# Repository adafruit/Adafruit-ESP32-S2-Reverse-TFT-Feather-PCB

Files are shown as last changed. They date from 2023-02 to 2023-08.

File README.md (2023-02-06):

## Adafruit ESP32-S2 Reverse TFT Feather PCB

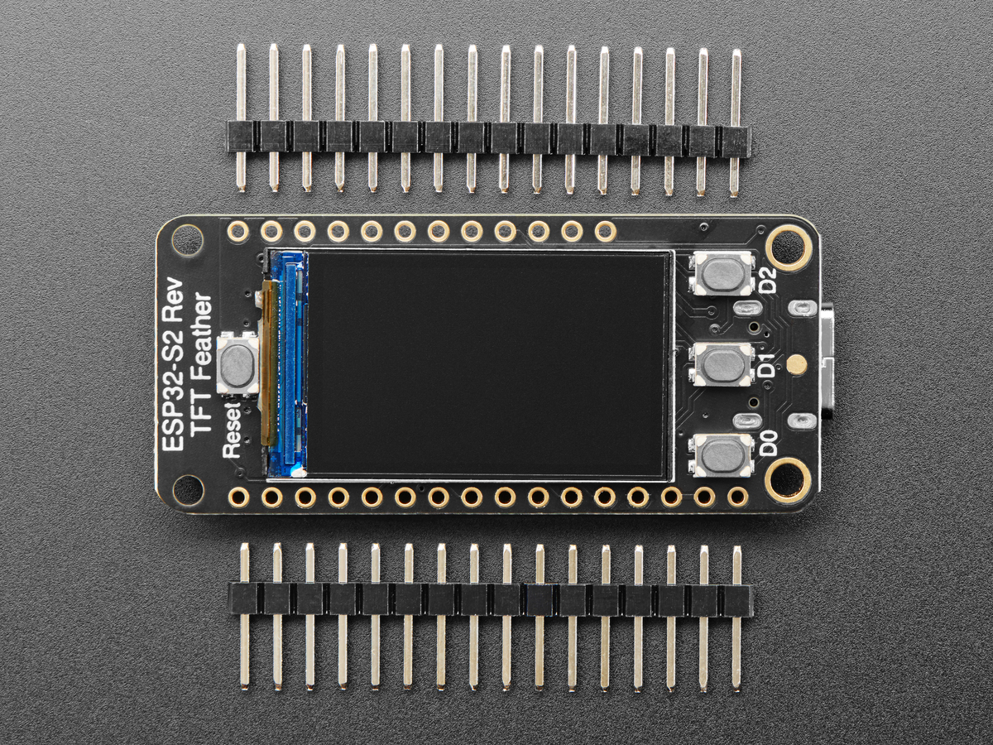
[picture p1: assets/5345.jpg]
<a href="http://www.adafruit.com/products/5345"><br/>
Click here to purchase one from the Adafruit shop</a>

PCB files for the Adafruit ESP32-S2 Reverse TFT Feather. 

Format is EagleCAD schematic and board layout
* https://www.adafruit.com/product/5345

### Description

Like Missy Elliot, we like to "put our [Feather] down, flip it and reverse it" and that's exactly what we've done with this new development board. It's basically our ESP32-S2 TFT Feather but with the 240x135 color TFT display on the back-side not the front-side. That makes it great for panel-mounted projects, particularly since we've also got some space for 3 buttons to go along. It's like an all-in-one display interface dev board, powered by the fantastic ESP32-S2 WIFI module.

This feather comes with native USB and 4 MB flash + 2 MB of PSRAM, so it is perfect for use with CircuitPython or Arduino with low-cost WiFi. Native USB means it can act like a keyboard or a disk drive. WiFi means it's awesome for IoT projects. And Feather means it works with the large community of Feather Wings for expandability.

The ESP32-S2 is a highly-integrated, low-power, 2.4 GHz Wi-Fi System-on-Chip (SoC) solution that now has built-in native USB as well as some other interesting new technologies like Time of Flight distance measurements. With its state-of-the-art power and RF performance, this SoC is an ideal choice for a wide variety of application scenarios relating to the Internet of Things (IoT), wearable electronics, and smart homes.

### License

Adafruit invests time and resources providing this open source design, please support Adafruit and open-source hardware by purchasing products from [Adafruit](https://www.adafruit.com)!

Designed by Limor Fried/Ladyada for Adafruit Industries.

Creative Commons Attribution/Share-Alike, all text above must be included in any redistribution. 
See license.txt for additional details.

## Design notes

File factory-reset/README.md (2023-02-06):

## Factory Reset file - ESP32-S2 Reverse TFT Feather

This is the factory reset file for the ESP32-S2 Reverse TFT Feather.

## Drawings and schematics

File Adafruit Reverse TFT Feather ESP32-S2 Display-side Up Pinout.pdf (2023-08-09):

# Adafruit ESP32-S2 Reverse TFT Feather

# https://www.adafruit.com/product/5345

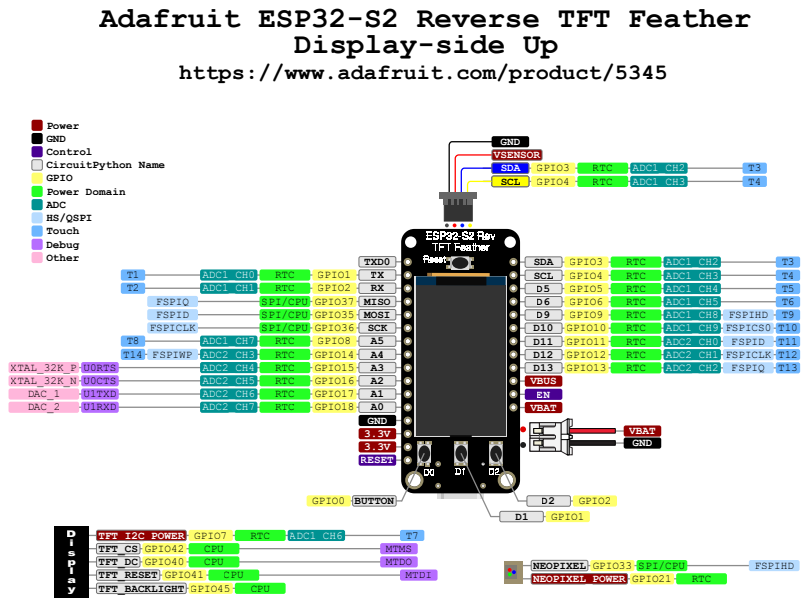
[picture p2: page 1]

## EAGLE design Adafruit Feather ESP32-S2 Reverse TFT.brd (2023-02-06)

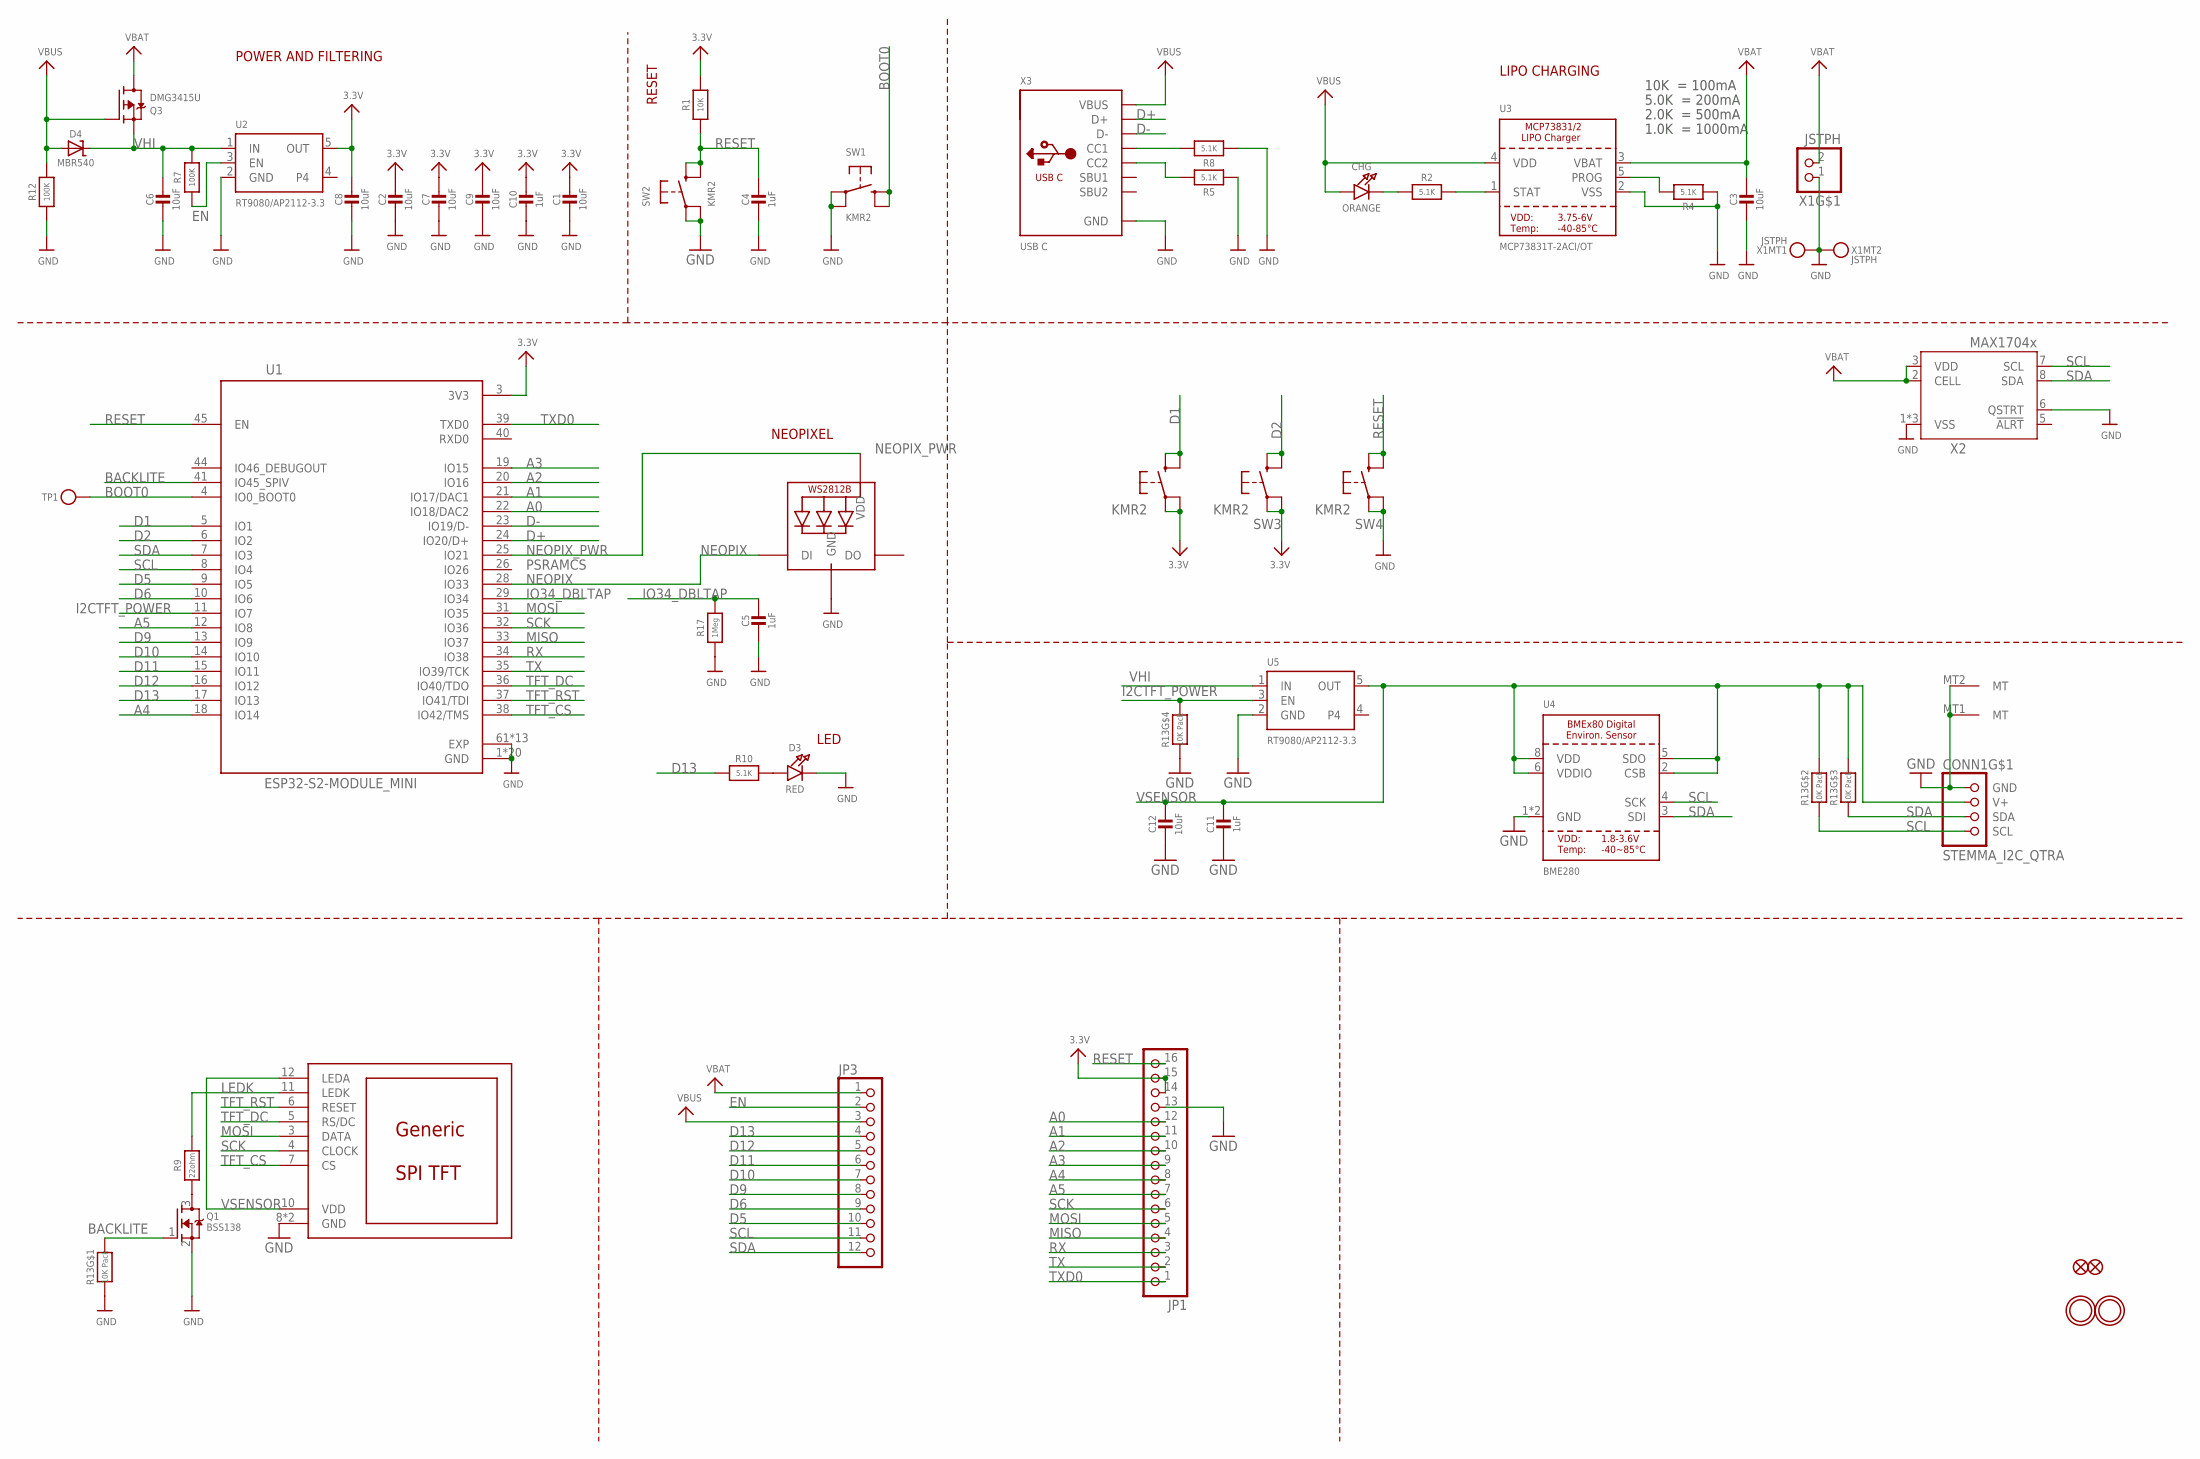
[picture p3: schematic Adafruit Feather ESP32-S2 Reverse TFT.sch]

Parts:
C1, C2, C3, C6, C7, C8, C9, C12: 10uF; 0805-NO
C4, C5, C10, C11: 1uF; 0603-NO
CHG: ORANGE; CHIPLED_0603_NOOUTLINE
CONN1: STEMMA_I2C_QTRA; JST_SH4_RA
D3: RED; CHIPLED_0603_NOOUTLINE
D4: MBR540; SOD-123
DISP1: DISP_LCD_GENERIC_SPI_1.14IN_240X135_WRAPUNDER; TFT_1.14IN_240X135_WRAPUNDER
JP1: HEADER-1X16_MIN; 1X16_ROUND_MIN
JP3: HEADER-1X12_MIN; 1X12_ROUND_MIN
LED1: WS2812B_SK6805_1515; SK6805_1515
Q1: BSS138; SC70
Q3: DMG3415U; SOT23-R
R1: 10K; 0603-NO
R2, R4, R5, R8, R10: 5.1K; 0603-NO
R7, R12: 100K; 0603-NO
R9: 22ohm; 0603-NO
R13: 10K Pack; RESPACK_4X0603
R17: 1Meg; 0603-NO
SW1, SW2, SW3, SW4, SW5: KMR2; BTN_RKB2_4.6X2.8
TP1: TESTPOINTROUND1.5MMNO; TESTPOINT_ROUND_1.5MM_NO
U1: ESP32-S2-MODULE_MINI; ESP32-S2-MINI-1
U2, U5: RT9080/AP2112-3.3; SOT23-5; JLC_ROTATION 0
U3: MCP73831T-2ACI/OT; SOT23-5
U4: BME280
U$31, U$32: MOUNTINGHOLE2.5; MOUNTINGHOLE_2.5_PLATED
U$34, U$35: FIDUCIAL_1MM
X1: JSTPH; JSTPH2_BATT
X2: MAX17048/T; TDFN8_2X2MM
X3: USB C; USB_C_CUSB31-CFM2AX-01-X

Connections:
3.3V: C1.1, C2.1, C7.1, C8.1, C9.1, C10.1, JP1.14, JP1.15, R1.2, SW3.A, SW3.A' (P1), SW5.A, SW5.A' (P1), U1.3 (3V3), U2.5 (OUT)
A0: JP1.12, U1.22 (IO18/DAC2)
A1: JP1.11, U1.21 (IO17/DAC1)
A2: JP1.10, U1.20 (IO16)
A3: JP1.9, U1.19 (IO15)
A4: JP1.8, U1.18 (IO14)
A5: JP1.7, U1.12 (IO8)
BACKLITE: Q1.1 (G), R13.8 (2), U1.41 (IO45_SPIV)
BOOT0: SW1.B (S), SW1.B' (S1), TP1.P$1, U1.4 (IO0_BOOT0)
D1: SW5.B (S), SW5.B' (S1), U1.5 (IO1)
D2: SW3.B (S), SW3.B' (S1), U1.6 (IO2)
D5: JP3.10, U1.9 (IO5)
D6: JP3.9, U1.10 (IO6)
D9: JP3.8, U1.13 (IO9)
D10: JP3.7, U1.14 (IO10)
D11: JP3.6, U1.15 (IO11)
D12: JP3.5, U1.16 (IO12)
D13: JP3.4, R10.1, U1.17 (IO13)
D+: U1.24 (IO20/D+), X3.A6 (D+), X3.B6 (D+)
D-: U1.23 (IO19/D-), X3.A7 (D-), X3.B7 (D-)
EN: JP3.2, R7.1, U2.3 (EN)
GND: C1.2, C2.2, C3.2, C4.2, C5.2, C6.2, C7.2, C8.2, C9.2, C10.2, C11.2, C12.2, CONN1.1 (GND), CONN1.MT1 (MT), CONN1.MT2 (MT), D3.C, DISP1.8 (GND), DISP1.13 (GND), JP1.13, LED1.4 (GND), Q1.2 (S), R4.1, R5.1, R8.1, R12.1, R13.1, R13.4 (1), R17.1, SW1.A, SW1.A' (P1), SW2.A, SW2.A' (P1), SW4.A, SW4.A' (P1), U1.1 (GND), U1.2 (GND), U1.30 (GND), U1.42 (GND), U1.43 (GND), U1.46 (GND), U1.47 (GND), U1.48 (GND), U1.49 (GND), U1.50 (GND), U1.51 (GND), U1.52 (GND), U1.53 (GND), U1.54 (GND), U1.55 (GND), U1.56 (GND), U1.57 (GND), U1.58 (GND), U1.59 (GND), U1.60 (GND), U1.61 (EXP), U1.62 (EXP), U1.63 (EXP), U1.64 (EXP), U1.65 (EXP), U1.66 (EXP), U1.67 (EXP), U1.68 (EXP), U1.69 (EXP), U1.70 (EXP), U1.71 (EXP), U1.72 (EXP), U1.73 (EXP), U2.2 (GND), U3.2 (VSS), U4.1 (GND), U4.7 (GND), U5.2 (GND), X1.1, X1.NC1, X1.NC2, X2.1 (VSS), X2.4 (VSS), X2.6 (QSTRT), X2.THERMAL (VSS), X3.A1B12 (GND), X3.B1A12 (GND)
I2CTFT_POWER: R13.5 (2), U1.11 (IO7), U5.3 (EN)
IO34_DBLTAP: C5.1, R17.2, U1.29 (IO34)
LEDK: DISP1.11 (LEDK), R9.2
MISO: JP1.4, U1.33 (IO37)
MOSI: DISP1.3 (DATA), JP1.5, U1.31 (IO35)
unnamed: CHG.C, R2.1
unnamed: Q1.3 (D), R9.1
unnamed: R2.2, U3.1 (STAT)
unnamed: R4.2, U3.5 (PROG)
unnamed: D3.A, R10.2
unnamed: R8.2, X3.A5 (CC1)
unnamed: R5.2, X3.B5 (CC2)
NEOPIX: LED1.1 (DI), U1.28 (IO33)
NEOPIX_PWR: LED1.2 (VDD), U1.25 (IO21)
RESET: C4.1, JP1.16, R1.1, SW2.B (S), SW2.B' (S1), SW4.B (S), SW4.B' (S1), U1.45 (EN)
RX: JP1.3, U1.34 (IO38)
SCK: DISP1.4 (CLOCK), JP1.6, U1.32 (IO36)
SCL: CONN1.4 (SCL), JP3.11, R13.2 (1), U1.8 (IO4), U4.4 (SCK), X2.7 (SCL)
SDA: CONN1.3 (SDA), JP3.12, R13.3 (1), U1.7 (IO3), U4.3 (SDI), X2.8 (SDA)
TFT_CS: DISP1.7 (CS), U1.38 (IO42/TMS)
TFT_DC: DISP1.5 (RS/DC), U1.36 (IO40/TDO)
TFT_RST: DISP1.6 (RESET), U1.37 (IO41/TDI)
TX: JP1.2, U1.35 (IO39/TCK)
TXD0: JP1.1, U1.39 (TXD0)
VBAT: C3.1, JP3.1, Q3.3 (D), U3.3 (VBAT), X1.2, X2.2 (CELL), X2.3 (VDD)
VBUS: CHG.A, D4.A, JP3.3, Q3.1 (G), R12.2, U3.4 (VDD), X3.A4B9 (VBUS), X3.B4A9 (VBUS)
VHI: C6.1, D4.C, Q3.2 (S), R7.2, U2.1 (IN), U5.1 (IN)
VSENSOR: C11.1, C12.1, CONN1.2 (V+), DISP1.10 (VDD), DISP1.12 (LEDA), R13.6 (2), R13.7 (2), U4.2 (CSB), U4.5 (SDO), U4.6 (VDDIO), U4.8 (VDD), U5.5 (OUT)

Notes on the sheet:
POWER AND FILTERING
RESET
10K = 100mA
5.0K = 200mA
2.0K = 500mA
1.0K = 1000mA
LIPO CHARGING
LED
PSRAMCS
NEOPIXEL

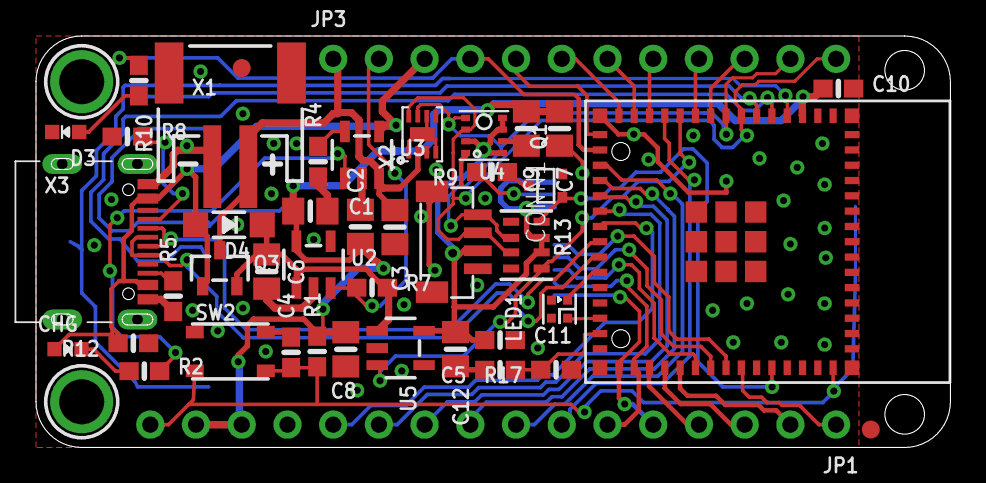
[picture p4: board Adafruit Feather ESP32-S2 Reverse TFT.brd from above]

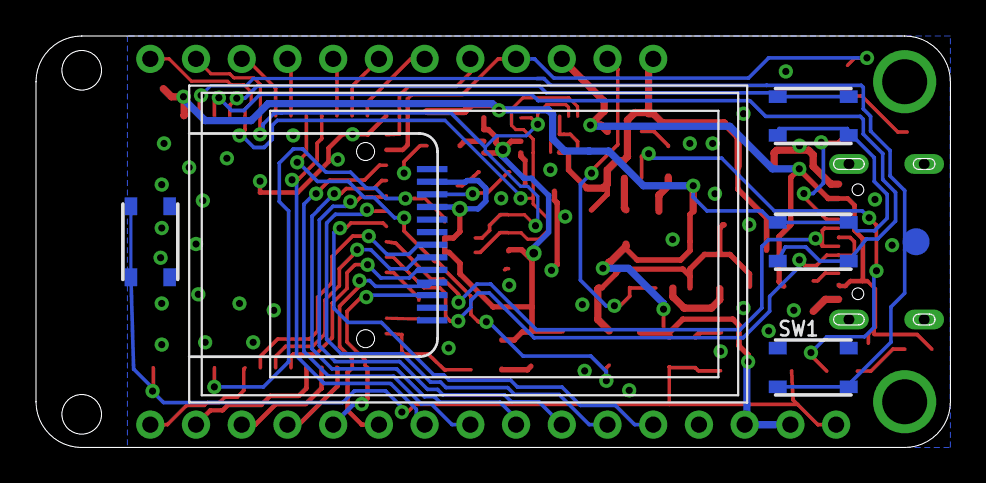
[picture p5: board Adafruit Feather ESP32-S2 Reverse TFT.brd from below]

Board: 2 copper layers, 50.8 x 22.9 mm, 88 parts (11 on the bottom side), 50 nets.

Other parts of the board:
PLABEL0: PLABEL0
PLABEL1: PLABEL1
PLABEL2: PLABEL2
PLABEL3: PLABEL3
PLABEL4: PLABEL4
PLABEL5: PLABEL5
PLABEL6: PLABEL6
PLABEL7: PLABEL7
PLABEL8: PLABEL8
PLABEL9: PLABEL9
PLABEL10: PLABEL10
PLABEL11: PLABEL11
PLABEL12: PLABEL12
PLABEL13: PLABEL13
PLABEL14: PLABEL14
PLABEL15: PLABEL15
PLABEL16: PLABEL16
PLABEL17: PLABEL17
PLABEL18: PLABEL18
PLABEL19: PLABEL19
PLABEL20: PLABEL20
PLABEL21: PLABEL21
PLABEL22: PLABEL22
PLABEL23: PLABEL23
PLABEL24: PLABEL24
PLABEL25: PLABEL25
PLABEL26: PLABEL26
PLABEL27: PLABEL27
PLABEL28: PLABEL28
PLABEL29: PLABEL29
PLABEL30: PLABEL30
PLABEL31: PLABEL31
PLABEL32: PLABEL32
PLABEL33: PLABEL33
PLABEL34: PLABEL34
PLABEL35: PLABEL35
PLABEL36: PLABEL36

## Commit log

2023-02-06 Added board files
    [Adafruit Feather ESP32-S2 Reverse TFT.brd, Adafruit Feather ESP32-S2 Reverse TFT.sch]
2023-08-09 Now with correct pin information!

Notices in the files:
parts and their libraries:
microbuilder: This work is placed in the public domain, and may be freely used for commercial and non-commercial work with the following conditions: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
